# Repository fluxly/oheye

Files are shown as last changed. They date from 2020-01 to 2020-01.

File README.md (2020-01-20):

# oheye
Oh Eye for Raspberry Pi 

16 analog inputs for the Pi. Requires SPI to be enabled in the Pi's configuration. Uses two MCP3008 10-bit A to D converters.

There's a Python library on the Python Package Index (https://pypi.org/project/oheye/) that you can install from the command line with Pip:

<pre>  sudo pip install oheye</pre>
  
Take a look at the ohEyePython directory for a few examples:

<pre>
#!/usr/bin/python

from oheye import analog_in 
import time

while True:
    for i in range(15):
        value = analog_in.read(i)
        print "%4d" % value,
    time.sleep(0.2)
    print;
</pre>

You can also use the Pd example in that directory to use the ohEye from Pure Data. That requires the WiringPi Pd external:

 http://nyu-waverlylabs.org/rpi-gpio/

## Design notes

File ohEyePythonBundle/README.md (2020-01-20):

# Oh Eye 16 Analog Inputs for Raspberry Pi

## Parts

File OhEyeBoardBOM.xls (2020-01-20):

OH EYE for Raspberry Pi
Component | No Req | Value | Description | Package | Supplier | PartNumber | Price ea per 100 | Total cost | Notes:
 | 2 | 10uF |  |  |  |  | $0.09 | $0.18 | 0.180
 | 3 | .1uF |  |  |  |  | $0.01 | $0.03 | 0.030
 | 1 | Yellow | LED |  |  |  | $0.09 | $0.09 | 0.090
 | 1 | 1k |  |  |  |  | $0.01 | $0.01 | 0.010
 | 1 | MCP1802 vreg |  |  |  |  | $0.40 | $0.40 | 0.4
 | 2 | MCP3008 |  |  |  |  | $1.66 | $3.32 | 3.32
 | 1 | 1x6 male header rt. |  |  |  |  |  | $0.00 | 0.060
 | 1 | 1x4 male header |  |  |  |  |  | $0.00 | 0.040
 | 12 | 2x3 male header |  |  |  |  | $0.06 | $0.72 | 0.250
 | 1 | PCB |  |  |  |  | $1.50 | $1.50 | 1.200
 | 1 | extra long Rasp Pi header |  |  |  |  | $0.35 | $0.35 | 0.2
Assembly Labor | 1 |  |  |  |  |  | 1.500 | $1.00 | 1.000
Packaging | 1 |  |  |  |  |  | 0.25 | 0.250 | 0.250
Shipping | 1 |  |  |  |  |  | 10.00% | 0.660 | 0.670
Total cost ea |  |  |  |  |  |  |  | $8.51 | $7.70
Wholesale |  |  |  |  |  |  |  | $14.18 | $12.83
Retail |  |  |  |  |  |  |  | $23.64 | $19.74
OH EYE ZERO for Raspberry Pi
Component | No Req | Value | Description | Package | Supplier | PartNumber | Price ea per 100 | Total cost
 | 4 | 10uF |  |  |  |  | $0.09 | $0.36
 | 5 | .1uF |  |  |  |  | $0.01 | $0.05
 | 1 | Yellow | LED |  |  |  | $0.09 | $0.09
 | 1 | 1k |  |  |  |  | $0.01 | $0.01
 | 1 | MCP1802 vreg |  |  |  |  | $0.40 | $0.40
 | 2 | MCP3008 |  |  |  |  | $1.66 | $3.32
 | 1 | 1x6 male header rt. |  |  |  |  | $0.06 | $0.06
 | 0 | 1x4 male header |  |  |  |  | $0.04 | $0.00
 | 8 | 2x3 male header |  |  |  |  | $0.06 | $0.48
 | 1 | PCB |  |  |  |  | $1.00 | $1.00
 | 1 | extra long Rasp Pi header |  |  |  |  | $0.35 | $0.35
 | 1 | mini audio jack |  |  |  | sc1489-1-nd | $0.66 | $0.66
Assembly Labor | 1 |  |  |  |  |  | 1.000 | $1.00
Packaging | 1 |  |  |  |  |  | 0.25 | 0.250
Shipping | 1 |  |  |  |  |  | 10.00% | 0.612
Total cost ea |  |  |  |  |  |  |  | $8.64
Wholesale |  |  |  |  |  |  |  | $14.40
Retail |  |  |  |  |  |  |  | $24.01
Perk levels | Cost | Price | Fees | Net | Profit | Number | Percent profit
1 | $2.00 | $10.00 | $1.00 | $9.00 | $7.00 | 10.00 | 22.22222222%
2 | $8.64 | $19.00 | $1.72 | $17.28 | $8.64 | 500.00 | 50.01157407%
3 | $9.12 | $20.00 | $1.80 | $18.20 | $9.08 | 50.00 | 50.10989011% | 688-RK09L114001T
4 | $16.82 | $37.00 | $3.16 | $33.84 | $17.02 | 10.00 | 49.70449173% | Pot | Cable
5 | $18.24 | $40.00 | $3.40 | $36.60 | $18.36 | 10.00 | 49.83606557% | 20 | 18
6 | $47.12 | $102.00 | $8.36 | $93.64 | $46.52 | 10.00 | 50.32037591%
7 | $94.24 | $204.00 | $16.52 | $187.48 | $93.24 | 10.00 | 50.26669511%
 |  |  |  |  |  | 600.00
 |  |  |  |  | Profit | 6594.4
 |  |  |  |  | Total income | 14430

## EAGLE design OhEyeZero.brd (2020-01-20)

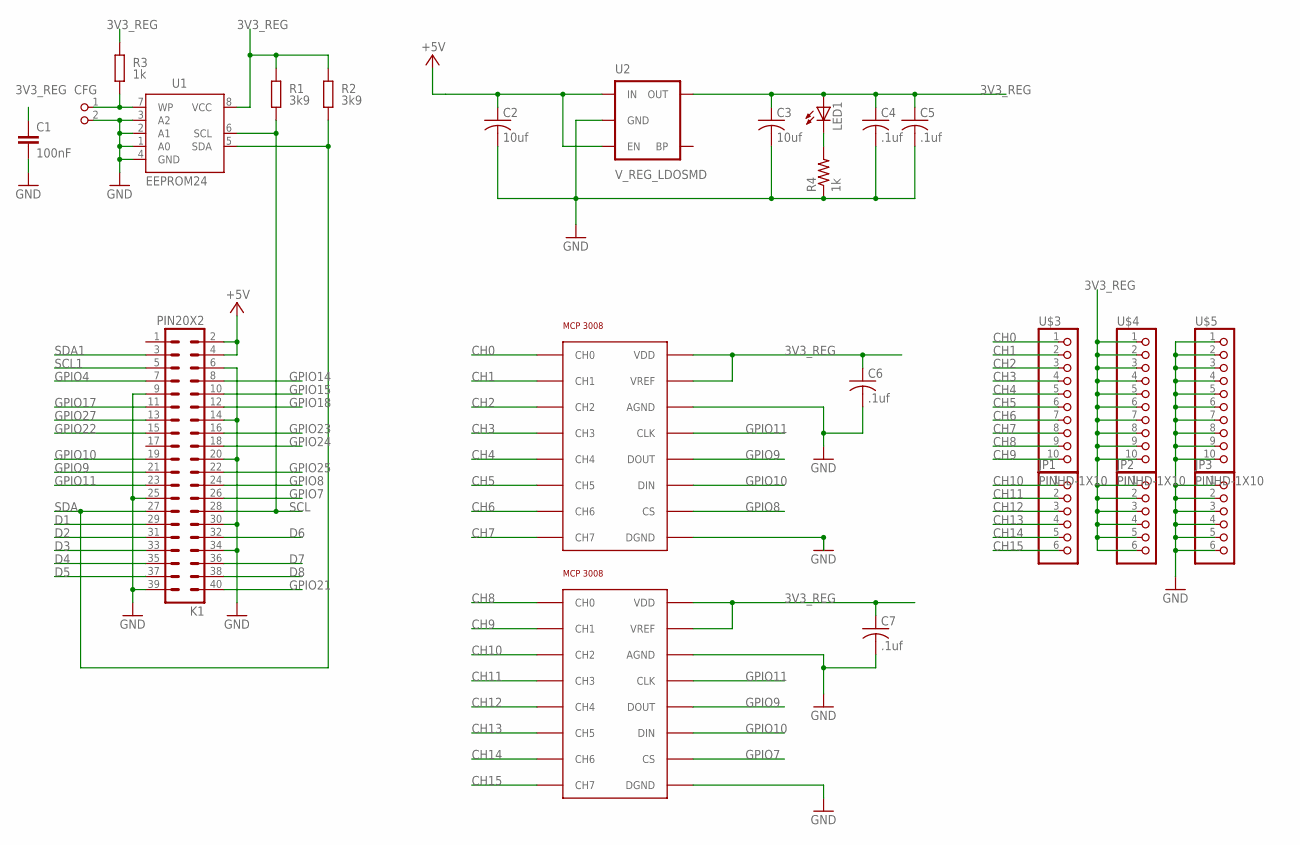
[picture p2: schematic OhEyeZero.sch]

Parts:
C1: 100nF; C0805K
C2, C3: 10uf; C0805K
C4, C5, C6, C7: .1uf; C0805K
CFG: PIN2_100; PIN_W_2
JP1, JP2, JP3: PINHD-1X6B; 1X06-BIG
K1: PIN20X2; PIN_20X2
LED1: LEDLED-0805; LED0805.PAC
R1, R2: 3k9; M0805; TOLERANCE 5%
R3: 1k; M0805; TOLERANCE 5%
R4: 1k; R0805W
U1: EEPROM24; SOIC8
U2: V_REG_LDOSMD; SOT23-5
U$1, U$2: MCP3008_ADC; SOIC16
U$3, U$4, U$5: PINHD-1X10; 1X10-BIG

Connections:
3V3_REG: C1.1, C3.1, C4.1, C5.1, C6.1, C7.1, JP2.1, JP2.2, JP2.3, JP2.4, JP2.5, JP2.6, LED1.A, R1.2, R2.2, R3.2, U1.8 (VCC), U2.5 (OUT), U$1.P$15 (VREF), U$1.P$16 (VDD), U$2.P$15 (VREF), U$2.P$16 (VDD), U$4.1, U$4.2, U$4.3, U$4.4, U$4.5, U$4.6, U$4.7, U$4.8, U$4.9, U$4.10
+5V: C2.1, K1.2, K1.4, U2.1 (IN), U2.3 (EN)
CH0: U$1.P$1 (CH0), U$3.1
CH1: U$1.P$2 (CH1), U$3.2
CH2: U$1.P$3 (CH2), U$3.3
CH3: U$1.P$4 (CH3), U$3.4
CH4: U$1.P$5 (CH4), U$3.5
CH5: U$1.P$6 (CH5), U$3.6
CH6: U$1.P$7 (CH6), U$3.7
CH7: U$1.P$8 (CH7), U$3.8
CH8: U$2.P$1 (CH0), U$3.9
CH9: U$2.P$2 (CH1), U$3.10
CH10: JP1.1, U$2.P$3 (CH2)
CH11: JP1.2, U$2.P$4 (CH3)
CH12: JP1.3, U$2.P$5 (CH4)
CH13: JP1.4, U$2.P$6 (CH5)
CH14: JP1.5, U$2.P$7 (CH6)
CH15: JP1.6, U$2.P$8 (CH7)
D1: K1.29
D2: K1.31
D3: K1.33
D4: K1.35
D5: K1.37
D6: K1.32
D7: K1.36
D8: K1.38
GND: C1.2, C2.2, C3.2, C4.2, C5.2, C6.2, C7.2, CFG.2, JP3.1, JP3.2, JP3.3, JP3.4, JP3.5, JP3.6, K1.6, K1.9, K1.14, K1.20, K1.25, K1.30, K1.34, K1.39, R4.1, U1.1 (A0), U1.2 (A1), U1.3 (A2), U1.4 (GND), U2.2 (GND), U$1.P$9 (DGND), U$1.P$14 (AGND), U$2.P$9 (DGND), U$2.P$14 (AGND), U$5.1, U$5.2, U$5.3, U$5.4, U$5.5, U$5.6, U$5.7, U$5.8, U$5.9, U$5.10
GPIO4: K1.7
GPIO7: K1.26, U$2.P$10 (CS)
GPIO8: K1.24, U$1.P$10 (CS)
GPIO9: K1.21, U$1.P$12 (DOUT), U$2.P$12 (DOUT)
GPIO10: K1.19, U$1.P$11 (DIN), U$2.P$11 (DIN)
GPIO11: K1.23, U$1.P$13 (CLK), U$2.P$13 (CLK)
GPIO14: K1.8
GPIO15: K1.10
GPIO17: K1.11
GPIO18: K1.12
GPIO21: K1.40
GPIO22: K1.15
GPIO23: K1.16
GPIO24: K1.18
GPIO25: K1.22
GPIO27: K1.13
unnamed: CFG.1, R3.1, U1.7 (WP)
unnamed: LED1.K (C), R4.2
SCL: K1.28, R1.1, U1.6 (SCL)
SCL1: K1.5
SDA: K1.27, R2.1, U1.5 (SDA)
SDA1: K1.3

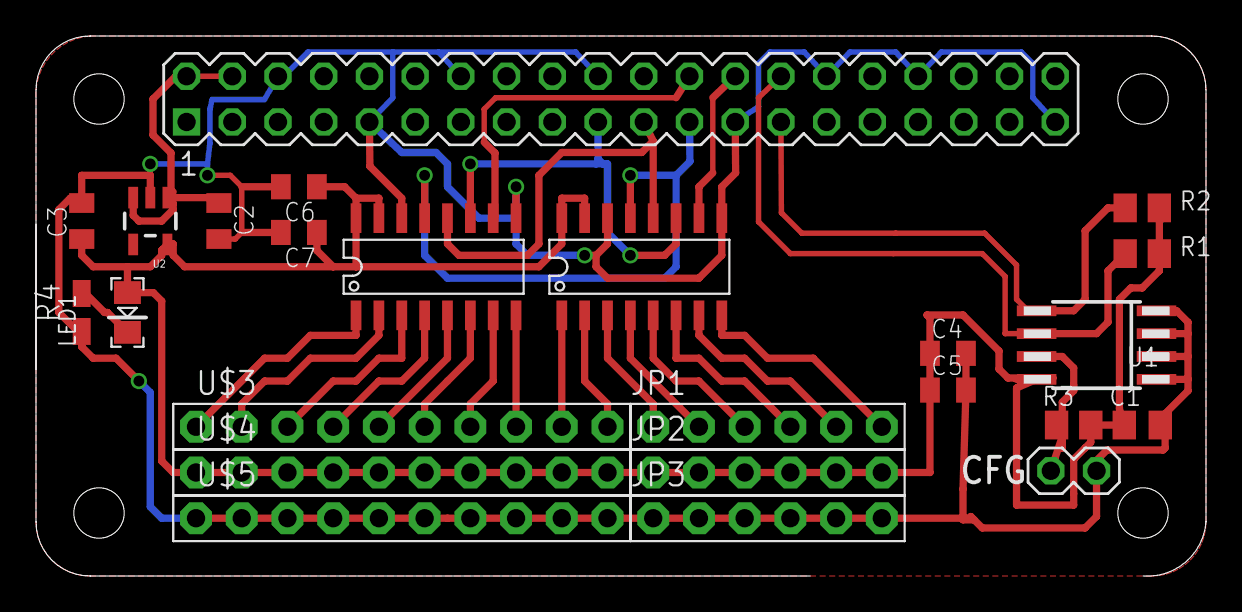
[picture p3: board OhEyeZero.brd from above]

Board: 2 copper layers, 65.0 x 30.0 mm, 24 parts (0 on the bottom side), 28 nets.

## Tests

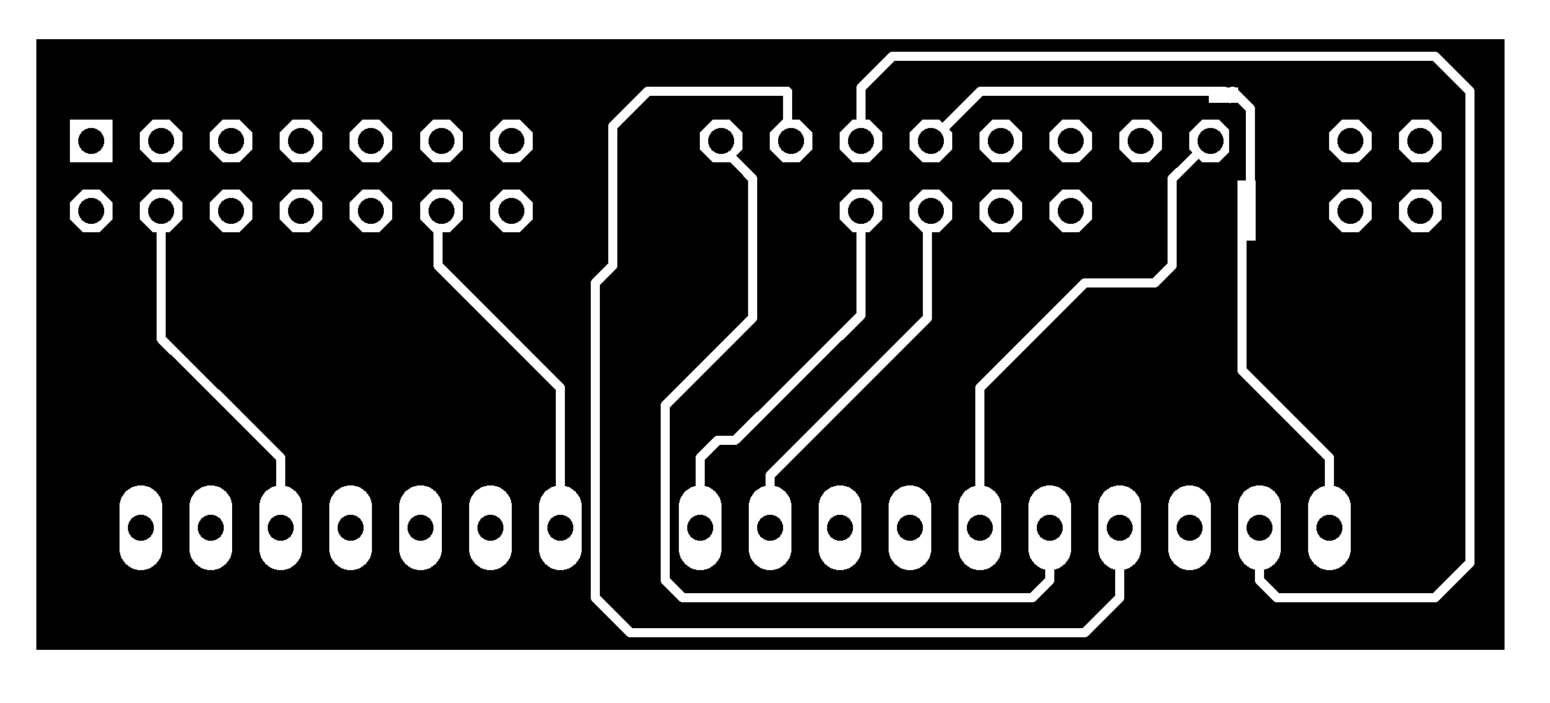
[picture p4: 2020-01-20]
OhEyeTester.png

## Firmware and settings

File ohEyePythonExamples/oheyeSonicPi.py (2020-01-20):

#!/usr/bin/python

import spidev
from random import random
from time import sleep
from pythonosc import osc_message_builder
from pythonosc import udp_client

sender = udp_client.SimpleUDPClient('127.0.0.1', 4559)


spi=spidev.SpiDev()
spi.open(0, 0)

def readADC(channel):
    if channel >15 or channel<0:
        return -1
    r=spi.xfer2([1, 8+channel<<4, 0])
    v=((r[1]&3)<<8)+r[2]
    print(v)
    return v

while True:
    pitch = readADC(0)
    
    sender.send_message('/osc_msg', pitch)
    <F12><F11>
sleep(.2)
